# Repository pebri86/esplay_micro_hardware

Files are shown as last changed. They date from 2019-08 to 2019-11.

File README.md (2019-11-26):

# ESPlay Micro Hardware
This board is micro version (smaller device but same as powerfull as big brother EsPlay Hardware), an ESP 32 Based portable gaming console. See the project logs at my [hackaday] page. Also if you want this board without much effort, you can buy it at [Makerfabs Online Store] they sell the PCB Assembly so you can get the board which ready to play.
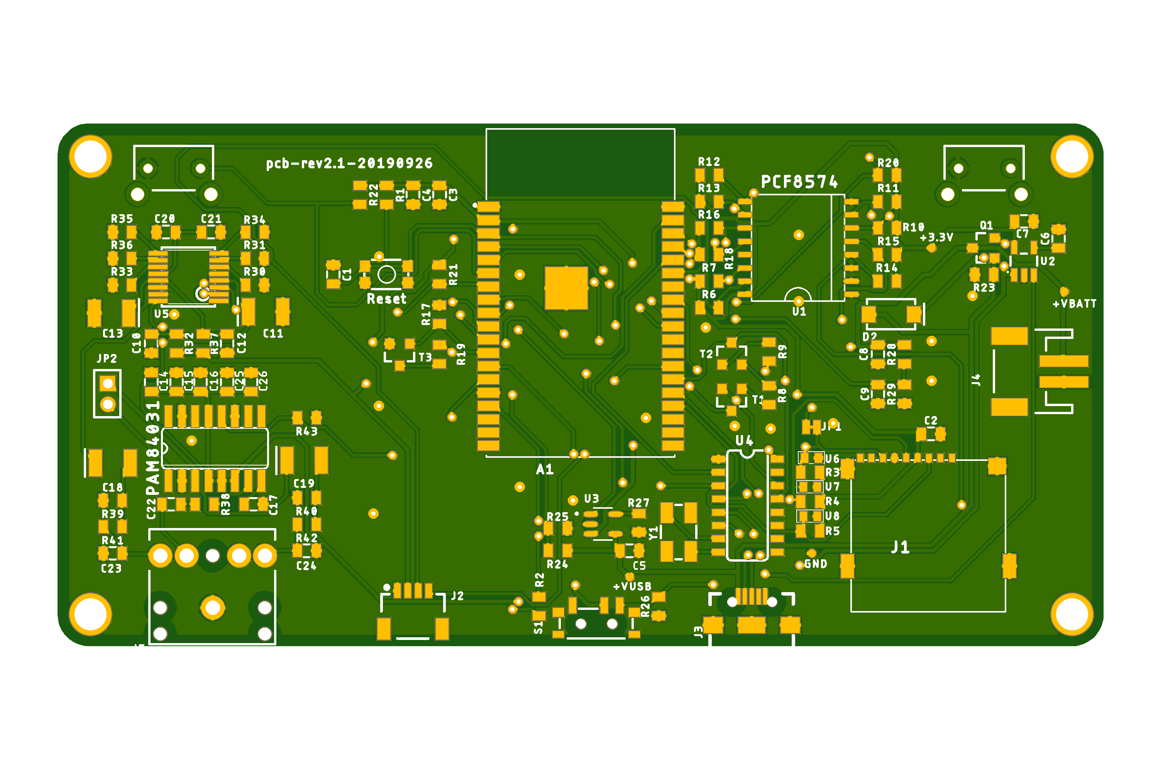
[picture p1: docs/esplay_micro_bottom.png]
bottom_layer

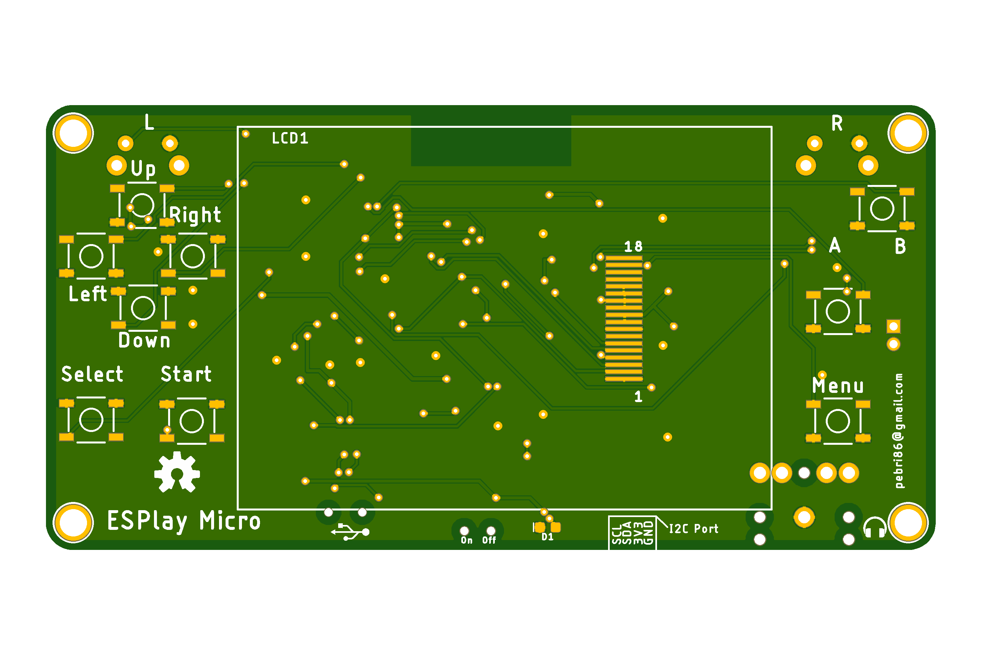
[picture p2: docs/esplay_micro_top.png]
top_layer


Featured
--------
- ESP32 WROVER, Dual core processor with Integrated 4MB Flash + 4MB PSRAM
- Integrated WIFI and Bluetooth 4 BLE
- 2,4" ILI9341 TFT Panel
- More button (expanded via PCF8574 I2C GPIO)
- Micro SD slot connected to SDMMC Host in 1 Line Mode for save GPIO pin
- Integrated I2S DAC via UDA1334A
- Integrated USB to Serial for programming and debugging using CH340C/G
- Built-in ~~TP4056~~ LTC4054 Li-Po charger
- ~~Touchscreen, yes resitive touchscreen of ili9341 now connected to ESP32 GPIO~~
- I2C port for expandable function
- 3,5mm Headphone jack
- Smaller Size, PCB only 100 x 50 mm.

Firmwares
---------
Flash this board with this [bootloader] for the ability flashing via sdcard, so you doesn't need computer to switch application firmware, and last but not least the emulator itself for playing the game [ESPlay Retro Emulation].

There is also collections of available compiled firmware (.fw) application files on my repo [Firmware Collections]

Changelogs
----------
### 01 Oct 2019
- Bugs fix brighness control issue
- Bugs fix autoreset circuit
- Bugs fix audiojack placement

### 27 Aug 2019
- Remove touchscreen control due to other function that more important
- Audio amplifier shutdown
- Audio amplifier chip change to PAM8304
- Change li-po charger with LTC4054
- Add Charger management sensing (USB plug and Chrge state)
- Add ESD Protection on SDCard
- Add status LED (charging) controlled via ESP32 GPIO

### 06 May 2019
- Add amplifier circuits for internal speaker.
- Add ground for EXP pin ESP32 Wrover module.
- Connect micro usb shield to ground.
- Remove some unnecessary vias.

[Makerfabs Online Store]: https://www.makerfabs.com/esplay-micro.html
[hackaday]: https://hackaday.io/project/166707-esplay-micro
[bootloader]: https://github.com/pebri86/esplay-base-firmware
[ESPlay Retro Emulation]: https://github.com/pebri86/esplay-retro-emulation
[Firmware Collections]: https://github.com/pebri86/esplay-micro-firmware-collections

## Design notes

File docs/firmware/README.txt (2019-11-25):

How to deploy bootloader and emulation firmware to ESPlay Micro

Preparation
-----------

1. Micro USB Cable
2. Micro SDCard
3. Install esptool
   >pip install esptool

Installation
------------

1. open the firmware folder and execute flash.bat under windows or flash.sh under linux (don't forget to make it executable first by chmod +x).
2. if the operation success the esplay will boot into bootloader menu.
3. copy esplay, mp3 and roms folder to root of microsd card.
4. put the card to ESPlay Micro sdcard slot.
5. turn on the board and the bootloader will show list of firmware file available in this case it will display esplay-retro-emu.fw and mp3-player_DAC.fw
6. To flash the firmware select the file then press A then Start, wait until flashing done then it will automatically restart and boot to application.
7. Place the rom of emulator on roms folder to the appropriate folder example game gear rom to gg folder, gameboy rom to gb folder and so on.

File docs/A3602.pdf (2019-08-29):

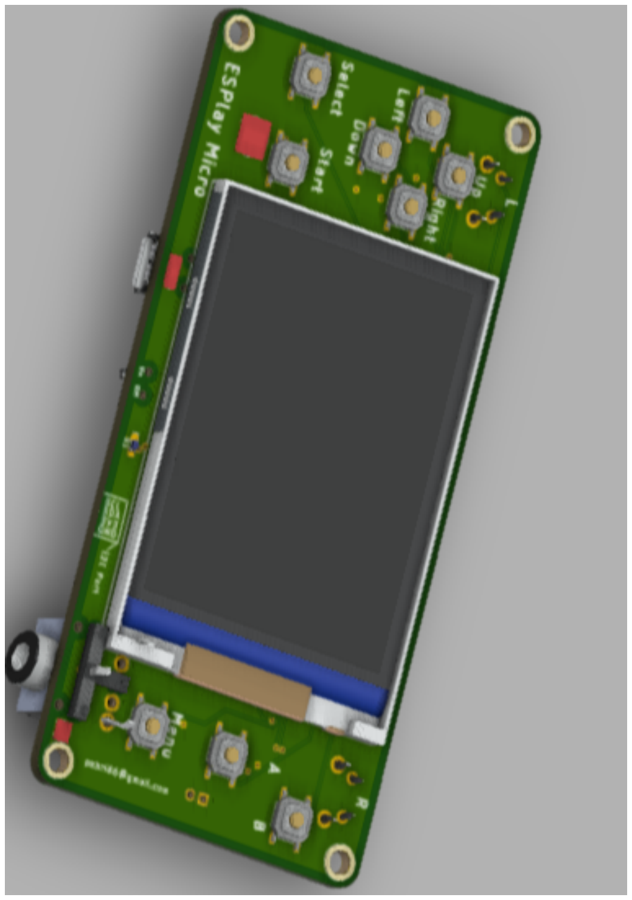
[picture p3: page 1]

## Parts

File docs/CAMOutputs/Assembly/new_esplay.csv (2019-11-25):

Qty | Value | Device | Package | Parts | Description | AVAILABILITY | BOM | DESCRIPTION | DIGI-KEY_PART_NUMBER | DIGI-KEY_PURCHASE_URL | MF | MP | PACKAGE | PRICE | PROD_ID | SF_ID | SF_SKU | VALUE
1 |  | JST_2MM_MALE | JST-2-SMD | J4 | JST 2MM MALE RA CONNECTOR |  |  |  |  |  |  |  |  |  | CONN-11443 | PRT-08612
9 |  | MOMENTARY-SWITCH-SPST-2-SMD-5.2MM | TACTILE_SWITCH_SMD_5.2MM | S2, S3, S4, S5, S6, S7, S8, S9, S11 | Momentary Switch (Pushbutton) - SPST - Two Circuits |  |  |  |  |  |  |  |  |  | SWCH-08247 |  | COM-08720
1 |  | PINHD-1X2_2.00 | 1X02M | JP2 | PIN HEADER
1 |  | QWIIC_CONNECTORJS-1MM | 1X04_1MM_RA | J2 | SparkFun I2C Standard Qwiic Connector |  |  |  |  |  |  |  |  |  | CONN-13694
1 |  | SWITCH-SPDT-SMD-RIGHT-ANGLE | SWITCH_SPST_SMD_A | S13 | Single Pole, Double Throw (SPDT) Switch |  |  |  |  |  |  |  |  |  | SWCH-10651 |  | COM-10860
1 |  | USB_MICRO-B_FEMALE-SMT | USB-B-MICRO-SMD | J3 | USB Type Micro-B Connector |  |  |  |  |  |  |  |  |  | CONN-11752
2 | 1 | 0.3OHM-0805-1/8W-1% | 0805 | R32, R37 | 0.3Ω resistor |  |  |  |  |  |  |  |  |  | RES-11622 |  |  | 0.3
1 | 1.1A/60V/600mΩ | MOSFET_PCH-SI2309DS | SOT23-3 | Q1 | P-channel MOSFETs |  |  |  |  |  |  |  |  |  | TRANS-08285 |  |  | 1.1A/60V/600mΩ
1 | 1.65K | 0.3OHM-0805-1/8W-1% | 0805 | R27 | 0.3Ω resistor |  |  |  |  |  |  |  |  |  | RES-11622 |  |  | 0.3
1 | 10 | 0.22OHM-0805-1/4W-1% | 0805 | R19 | 0.22Ω resistor |  |  |  |  |  |  |  |  |  | RES-09883 |  |  | 0.22
2 | 100 | 0.3OHM-0805-1/8W-1% | 0805 | R41, R42 | 0.3Ω resistor |  |  |  |  |  |  |  |  |  | RES-11622 |  |  | 0.3
2 | 100K | 0.22OHM-0805-1/4W-1% | 0805 | R17, R26 | 0.22Ω resistor |  |  |  |  |  |  |  |  |  | RES-09883 |  |  | 0.22
1 | 100K | 0.3OHM-0805-1/8W-1% | 0805 | R43 | 0.3Ω resistor |  |  |  |  |  |  |  |  |  | RES-11622 |  |  | 0.3
7 | 100nF | 2.2UF-0805-25V-(+80/-20%) | 0805 | C1, C4, C8, C9, C10, C12, C20 | 2.2µF ceramic capacitors |  |  |  |  |  |  |  |  |  | CAP-11624 |  |  | 2.2uF
18 | 10K | 0.22OHM-0805-1/4W-1% | 0805 | R1, R3, R4, R5, R8, R9, R10, R11, R12, R13, R14, R15, R16, R18, R20, R21, R22, R23 | 0.22Ω resistor |  |  |  |  |  |  |  |  |  | RES-09883 |  |  | 0.22
7 | 10K | 0.3OHM-0805-1/8W-1% | 0805 | R30, R31, R33, R34, R35, R36, R38 | 0.3Ω resistor |  |  |  |  |  |  |  |  |  | RES-11622 |  |  | 0.3
4 | 10nF | 2.2UF-0805-25V-(+80/-20%) | 0805 | C16, C17, C23, C24 | 2.2µF ceramic capacitors |  |  |  |  |  |  |  |  |  | CAP-11624 |  |  | 2.2uF
5 | 10uF | 2.2UF-0805-25V-(+80/-20%) | 0805 | C2, C7, C14, C21, C26 | 2.2µF ceramic capacitors |  |  |  |  |  |  |  |  |  | CAP-11624 |  |  | 2.2uF
1 | 12Mhz | CRYSTALSMD-5X3.2-4PAD | CRYSTAL-SMD-5X3.2-4PAD | Y1 | Crystals (Generic)
1 | 1A/40V/500mV | DIODE-SCHOTTKY-SS14 | SMA-DIODE | D2 | Schottky diode |  |  |  |  |  |  |  |  |  | DIO-08053 |  |  | 1A/40V/500mV
3 | 1uF | 2.2UF-0805-25V-(+80/-20%) | 0805 | C5, C15, C25 | 2.2µF ceramic capacitors |  |  |  |  |  |  |  |  |  | CAP-11624 |  |  | 2.2uF
1 | 2.2uF | 2.2UF-0805-25V-(+80/-20%) | 0805 | C3 | 2.2µF ceramic capacitors |  |  |  |  |  |  |  |  |  | CAP-11624 |  |  | 2.2uF
2 | 220K | 0.3OHM-0805-1/8W-1% | 0805 | R39, R40 | 0.3Ω resistor |  |  |  |  |  |  |  |  |  | RES-11622 |  |  | 0.3
1 | 220nF | 2.2UF-0805-25V-(+80/-20%) | 0805 | C22 | 2.2µF ceramic capacitors |  |  |  |  |  |  |  |  |  | CAP-11624 |  |  | 2.2uF
1 | 2K2 | 0.22OHM-0805-1/4W-1% | 0805 | R2 | 0.22Ω resistor |  |  |  |  |  |  |  |  |  | RES-09883 |  |  | 0.22
2 | 470K | 0.22OHM-0805-1/4W-1% | 0805 | R28, R29 | 0.22Ω resistor |  |  |  |  |  |  |  |  |  | RES-09883 |  |  | 0.22
1 | 470pF | 2.2UF-0805-25V-(+80/-20%) | 0805 | C6 | 2.2µF ceramic capacitors |  |  |  |  |  |  |  |  |  | CAP-11624 |  |  | 2.2uF
2 | 47K | 0.22OHM-0805-1/4W-1% | 0805 | R24, R25 | 0.22Ω resistor |  |  |  |  |  |  |  |  |  | RES-09883 |  |  | 0.22
4 | 47uF | 47UF-POLAR-EIA3528-10V-10% | EIA3528 | C11, C13, C18, C19 | 47µF polarized capacitors |  |  |  |  |  |  |  |  |  | CAP-08310 |  |  | 47uF
2 | 4K7 | 0.22OHM-0805-1/4W-1% | 0805 | R6, R7 | 0.22Ω resistor |  |  |  |  |  |  |  |  |  | RES-09883 |  |  | 0.22
3 | 600mA/40V | TRANS_NPN-MMBT2222AL | SOT23-3 | T1, T2, T3 | NPN transistor |  |  |  |  |  |  |  |  |  | TRANS-08049 |  |  | 600mA/40V
1 | AUDIO_JACK_3.5MM_PTH | AUDIO_JACK_3.5MM_PTH | AUDIO-JACK | J5 | Audio Jack |  |  |  |  |  |  |  |  |  | CONN-08774 | PRT-08032
1 | BLUE | LED-BLUE0603 | LED-0603 | D1 | Blue SMD LED |  |  |  |  |  |  |  |  |  | DIO-08575 |  |  | BLUE
1 | CH340G | CH340GSMD | SO016 | U4 | A simple USB 2.0 to Serial IC. |  |  |  |  |  |  |  |  |  | IC-13498 |  |  | CH340G
3 | ESD0402 | ESD0402 | ESD0402 | U6, U7, U8 | None
1 | ESP32-WROVER-I | ESP32-WROVER-I | XCVR_ESP32-WROVER-I | A1 | Module: combo; GPIO, I2C x2, I2S x2, SDIO, SPI x3, UART x3; U.FL | Unavailable |  | Module: combo | GPIO, I2C x2, I2S x2, SDIO, SPI x3, UART x3 | U.FL |  |  | Espressif Systems | ESP32-WROVER-I | Module Espressif Systems | None
1 | ILI9341-2.4 | ILI9341-2.4 | ILI9341-2.4 | LCD1
1 | JP Bootstrap | JUMPER-SMT_2_NC_TRACE_NO-SILK | SMT-JUMPER_2_NC_TRACE_NO-SILK | JP1 | Normally closed trace jumper
1 | L | MOMENTARY-SWITCH-SPST-PTH-RIGHT-ANGLE-KIT | TACTILE_SWITCH_PTH_RIGHT_ANGLE_KIT | S10 | Momentary Switch (Pushbutton) - SPST |  |  |  |  |  |  |  |  |  | CONN-10672 |  | COM-10791
1 | LTC4054LES5-4.2#TRPBF | LTC4054LES5-4.2#TRPBF | SOT95P280X100-5N | U3 | LTC4054L-4.2 - 150mA Standalone Linear Li-Ion Battery Charger in ThinSOT |  |  | LTC4054L-4.2 - 150mA Standalone Linear Li-Ion Battery Charger in ThinSOT | LTC4054LES5-4.2#TRPBFCT-ND | https://www.digikey.co.id/product-detail/en/linear-technology-analog-devices/LTC4054LES5-4.2-TRPBF/LTC4054LES5-4.2-TRPBFCT-ND/1888452 | Linear Technology/Analog | LTC4054LES5-4.2#TRPBF | SOT-23-5 Linear Technology
1 | MIC5219 3.3V | V_REG_MIC52193.3V | SOT23-5 | U2 | V_REG MIC5219 |  |  |  |  |  |  |  |  |  | VREG-09872 |  |  | MIC5219 3.3V
4 | MICROBUILDER_MOUNTINGHOLE3.0THIN | MICROBUILDER_MOUNTINGHOLE3.0THIN | MICROBUILDER_MOUNTINGHOLE_3.0_PLATEDTHIN | H1, H2, H3, H4 | Mounting Hole |  | EXCLUDE
1 | MICROSD-PUSH-OUT | MICROSD-PUSH-OUT | MICROSD-PUSH-OUT | J1 | T-Flash Push-Out Micro SD Card Reader
1 | PAM8403 | PAM8403 | SOP-16 | PAM84031 | Dual channel audio amplifier IC - PAM8403
1 | PCF8574 | PCF8574 | SO16 | U1 |  | Unavailable |  | Remote 8-Bit I/O Expander for I2C-Bus |  |  | Texas Instruments | PCF8574 | SOIC-16 Texas Instruments | None
1 | R | MOMENTARY-SWITCH-SPST-PTH-RIGHT-ANGLE-KIT | TACTILE_SWITCH_PTH_RIGHT_ANGLE_KIT | S12 | Momentary Switch (Pushbutton) - SPST |  |  |  |  |  |  |  |  |  | CONN-10672 |  | COM-10791
1 | RST | MOMENTARY-SWITCH-SPST-SMD-4.6X2.8MM | TACTILE_SWITCH_SMD_4.6X2.8MM | S1 | Momentary Switch (Pushbutton) - SPST |  |  |  |  |  |  |  |  |  | SWCH-13065
4 | TEST-POINT3 | TEST-POINT3 | PAD.03X.03 | TP1, TP2, TP3, TP4 | SparkFun Test Points
1 | UDA1334ATS | MICROBUILDER_AUDIO_I2S_UDA1334" | MICROBUILDER_SSOP16_4.4MM | U5 | UDA1334 I2C Audio DAC

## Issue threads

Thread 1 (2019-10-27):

Auto Reset circuit

gvoigtlaender, 2019-10-27:
Hi,

I wonder if the designed auto-reset circuit is working. On other schematics both DTR & RTS go to Base of one transistor and Emitter of other [1].
In esplay_micro schematic DTR goes to the Collector of T2. Is that on purpose?

[1] http://www.basicpi.org/wp-content/uploads/2018/02/ESP32_CH340G.png

BR,
Georg

pebri86, 2019-10-27:
Hi, thanks for opening an issue. Yes it is my mistake and I've updated the local files but not push to github yet, tomorrow i will update the repository. actually this board is already available on the makerfabs online store [Here](https://www.makerfabs.com/esplay-micro.html) and this board version should have the correct auto reset circuit.

thanks,
regards.

pebri86, 2019-10-28:
Hi, I've updated the repo. Thanks for reporting the issue.

Regards.

Closed 2019-10-28.

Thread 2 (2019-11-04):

Max brightness still too dark

pebri86, 2019-11-04:
**ISSUE DESCRIPTION**
Set brightness setting to maximum but it still too dark.

**How to reproduce**
Set brightness to maximum then check the LCD still too dark.

Hardware issue? or change duty max value (PWM)

Closed 2019-11-04.

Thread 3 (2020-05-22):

slow battery charging

pizvizdik, 2020-05-22:
hello pebri,

every battery i tried is charging only at 50mA rate which is pretty slow i think (about 20 hours of charging time with 1000mAh battery).. i also tried different usb power supplies and micro USB cables.. is it caused by scheme design or there is possible problem?

thank you

pebri86, 2020-05-24:
Hi,
Please check value of R27 it should be 1.65k to deliver 600mA charge rate.

pizvizdik, 2020-05-28:
hi, i just checked R27, resistance seems to be OK (about 1.66K).. still no higher current than 50mA.. do you have any other ideas please?

pebri86, 2020-05-29:
> hi, i just checked R27, resistance seems to be OK (about 1.66K).. still no higher current than 50mA.. do you have any other ideas please?

Try changing those Resistor with 1K value

pizvizdik, 2020-05-29:
thank you very much pebri ^^ i just soldered 1K resistor and charge rate goes up to about 100mA :3 not sure how to calculate R27 resistance for at least 800mA?

pebri86, 2020-05-30:
Ah, i think you have another variant of LTC4054 ic. I originally designed with LTC4054-4.2 which the datasheet said the charge current 1000 times the current out the PROG pin and the formula is

Rprog = 1000 / Ichrg

so if you have 1K value with result of 100mA then your LTC variant have 100 times not 1000. So Rprog = 100/Ichrg.

Which means to get 800mA try change rprog with 125 Ohm.

pizvizdik, 2020-06-14:
finaly had time to swap that little guy, now everything is working just fine :3
thank you very much for your help :)

Closed 2020-06-14.

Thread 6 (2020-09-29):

Missing BOM

ronangaillard, 2020-09-29:
Hi,

I'm pretty sur I saw a BOM for this project with DK References.

If I'm not mistaken could you add it to your repo ?

If not where can I find it ?

Thanks

pebri86, 2020-10-08:
Hi, sorry for waiting.
I've been busy for a while.
The BOM should be in the repository, check doc/camoutputs/assembly folder in CSV file.

ronangaillard, 2020-10-09:
Thanks !
I thought I found one with dk refs but I must be confused !

Closed 2020-10-09.

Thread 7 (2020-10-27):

The game in the NES emulator cannot be saved. What is the problem?

38293312, 2020-10-27:
The game in the NES emulator cannot be saved. What is the problem?

pebri86, 2020-11-02:
Hi,
I can't reproduce the issue, my build is working fine. So could you show the debug serial output? which version of esplay firmware did you use or which NES rom ( or is happen on all ROM ?).

38293312, 2020-11-02:
> 嗨，
> 我无法重现该问题，我的构建工作正常。那么，您可以显示调试串行输出吗？您使用了哪个版本的esplay固件或哪个NES rom（或在所有ROM上都发生了？）。

I am using "v2.2-esplay-micro.fw". IDF v3.3-202gefdddbb25-dirty. While the NES emulator and SEGA emulator are running the game, pressing the "menu" pop-up "volume" "brightness" "SAVE" in "SAVE" cannot save the game progress. In the process of saving the game in the SEGA emulator, the game can’t be saved or the "SAVE" in the "menu" button is pressed

pebri86, 2020-11-02:
Which ROM file did you play? I will tried reproduce the issue cause mine is no problem.

38293312, 2020-11-02:
> 您播放了哪个ROM文件？我会尝试重现该问题，因为我的没有问题。

I don't know whether "Contra.nes" can be saved normally on the NES emulator. SEGA has the same problem. I just tried the GBC game "pokemon gold.gbc" and it can’t be saved.

pebri86, 2020-11-02:
It's strange, could you show the folder structure on the sdcard? actually it's better if you can post the serial debug log.

38293312, 2020-11-02:
Show folder structure on my sdcard，I'm very sorry, I don't understand how the serial debug log is debugged, can you tell me?

     audio---*.mp3
     esplay---firmware
     roms---col
            |---gb
            |---bgc
            |---gg
            |---nes
            |---sms

38293312, 2020-11-02:
> 奇怪，您能在sdcard上显示文件夹结构吗？实际上，最好是可以发布串行调试日志。

Show folder structure on my sdcard，I'm very sorry, I don't understand how the serial debug log is debugged, can you tell me?

 audio---*.mp3
 esplay---firmware
 roms---col
        |---gb
        |---bgc
        |---gg
        |---nes
        |---sms

pebri86, 2020-11-02:
> I'm very sorry, I don't understand how the serial debug log is debugged, can you tell me?

You missing data folder under esplay folder, please make folder for each emulator system at esplay->data
for example data folder for nes system will be /esplay/data/nes.

38293312, 2020-11-02:
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

Hahaha, great, it turned out to be a problem caused by insufficient files. After your explanation, after I created the folder now, the NES archive is now normal. However, the archive of GBC and COL simulators is not normal after trying twice, and there is no SAV file in the corresponding GBC and COL folders. Strange!

38293312, 2020-11-02:
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

There is a GBC game that cannot be saved normally. It may be caused by the game ROM. I used another version and it is normal. Now there is no problem. Thank you for your help!

pebri86, 2020-11-02:
Great to hear that from you. Yes some rom are not fully compatible with the emulators but almost roms are compatible.

Now I'll close the issue.

Closed 2020-11-02.

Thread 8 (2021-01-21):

License

niutech, 2021-01-21:
What's the license of ESPlay Micro design files, bootloader and firmware? Is it open source?

pebri86, 2021-01-21:
Hi,
Yes the projects are open source,  you're free to modify and made your own based on this projects, but if you don't mind you can shared your modified version with us, so we can improve the projects together. Thank you

dunk8888, 2021-02-10:
Hi what was the problem with resistor, my backlight doesnt work when using mp3 player, also most firmware. My resistor value says 100. Witch is 10 ohm i think, do i need to switch it out?

Aleyhanz, 2025-07-26:
Hi kak Pebri,apakah bisa custom project untuk TFT 8 bit

Aleyhanz, 2025-07-26:
Apakah support lcd 8bit.dengan keterbatasan pinout esp32.thank you

Pada Sab, 26 Jul 2025 21.50, Fuji Pebri ***@***.***> menulis:

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

Aleyhanz, 2025-07-28:
Saya masih belum paham dengan esp-idf .barangkali kakak  bersedia bikin project untuk TFT 8bit.
Rencana pakai lcd ili9341 8bit dan esp32s3 N16R8 dev modul yg banyak GPIO nya.thanks kak

Aleyhanz, 2025-08-02:
Maaf kak apakah firmware ini ada versi binariesnya

pebri86, 2025-08-04:
ada di sini [esplay retro emulation](https://www.google.com/url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)

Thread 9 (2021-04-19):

BOM table display error

LuckyFishGeek, 2021-04-19:
I use Office 2013 to open the display seems incorrect.Or is my Character Encoding set?

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

Thank you this very good project

pebri86, 2021-04-19:
Hi, maybe your encoding or try using import the csv file instead opening it.

Closed 2021-04-19.

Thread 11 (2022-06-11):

Is there a problem that the CS(Chip Select) pin of TF card is not connected?

eggfly, 2022-06-11:
As title 😄
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

pebri86, 2022-06-11:
i designed it using 1-bit sdmmc connection mode and the cs pin is not required.

eggfly, 2022-06-11:
OH I understand now. And when using sdmmc mode these three sdio is also a must?

pebri86, 2022-06-11:
> OH I understand now. And when using sdmmc mode these three sdio pull up resistors are also a must? Beside SPI mode three resistors is not needed.

yes you're right you can read idf documentation for details how to work with sdcard with sdmmc mode and sdspi mode

eggfly, 2022-06-12:
Thank u very much.

Closed 2022-06-12.

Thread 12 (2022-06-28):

ILI9342 smaller screen?

eggfly, 2022-06-28:
Hi! Thank you for such a great project! I have a small question: I found this ILI9342 source code in firmware project:
https://github.com/pebri86/esplay-retro-emulation/blob/cf68ea80ea34987592b4fb1ba650a074ea85b839/esplay-sdk/esplay-components/esplay-hal/src/ili9342.c

Does that mean we can switch to a smaller screen than 2.4-inch screen (2.0-inch 320x240 TFT screen)?

Thank you!

32teeth, 2022-07-01:
> ILI9342 Support

Yes, any ILI934/C LCD will work with this.

> Things to consider

If it is a **C** variant (ILI9342C) there are a few addresses to add / omit. Take a look at our [odroid_display.c](https://github.com/retro-esp32/RetroESP32/blob/master/Launchers/retro-esp32/components/odroid/odroid_display.c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) specifically [this line](https://github.com/retro-esp32/RetroESP32/blob/master/Launchers/retro-esp32/components/odroid/odroid_display.c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)

```
{0x36, {(MADCTL_MX | MADCTL_MY | TFT_RGB_BGR)}, 1},
```

Closed 2022-06-28.

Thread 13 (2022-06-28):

What is the JP1 bootstrap between IO2 and IO0 used for?

eggfly, 2022-06-28:
Hi, I'm learning the ESPlay hardware design, I found this jumper between tf card's `dat0` pin and IO0 pin, what is it used for?

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

Forgive me for using the issue system to discuss my question, and thank you very much!

eggfly, 2022-06-28:
Oh I see this 😄:

https://docs.espressif.com/projects/esp-idf/en/latest/esp32/api-reference/peripherals/sd_pullup_requirements.html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

Closed 2022-06-29.

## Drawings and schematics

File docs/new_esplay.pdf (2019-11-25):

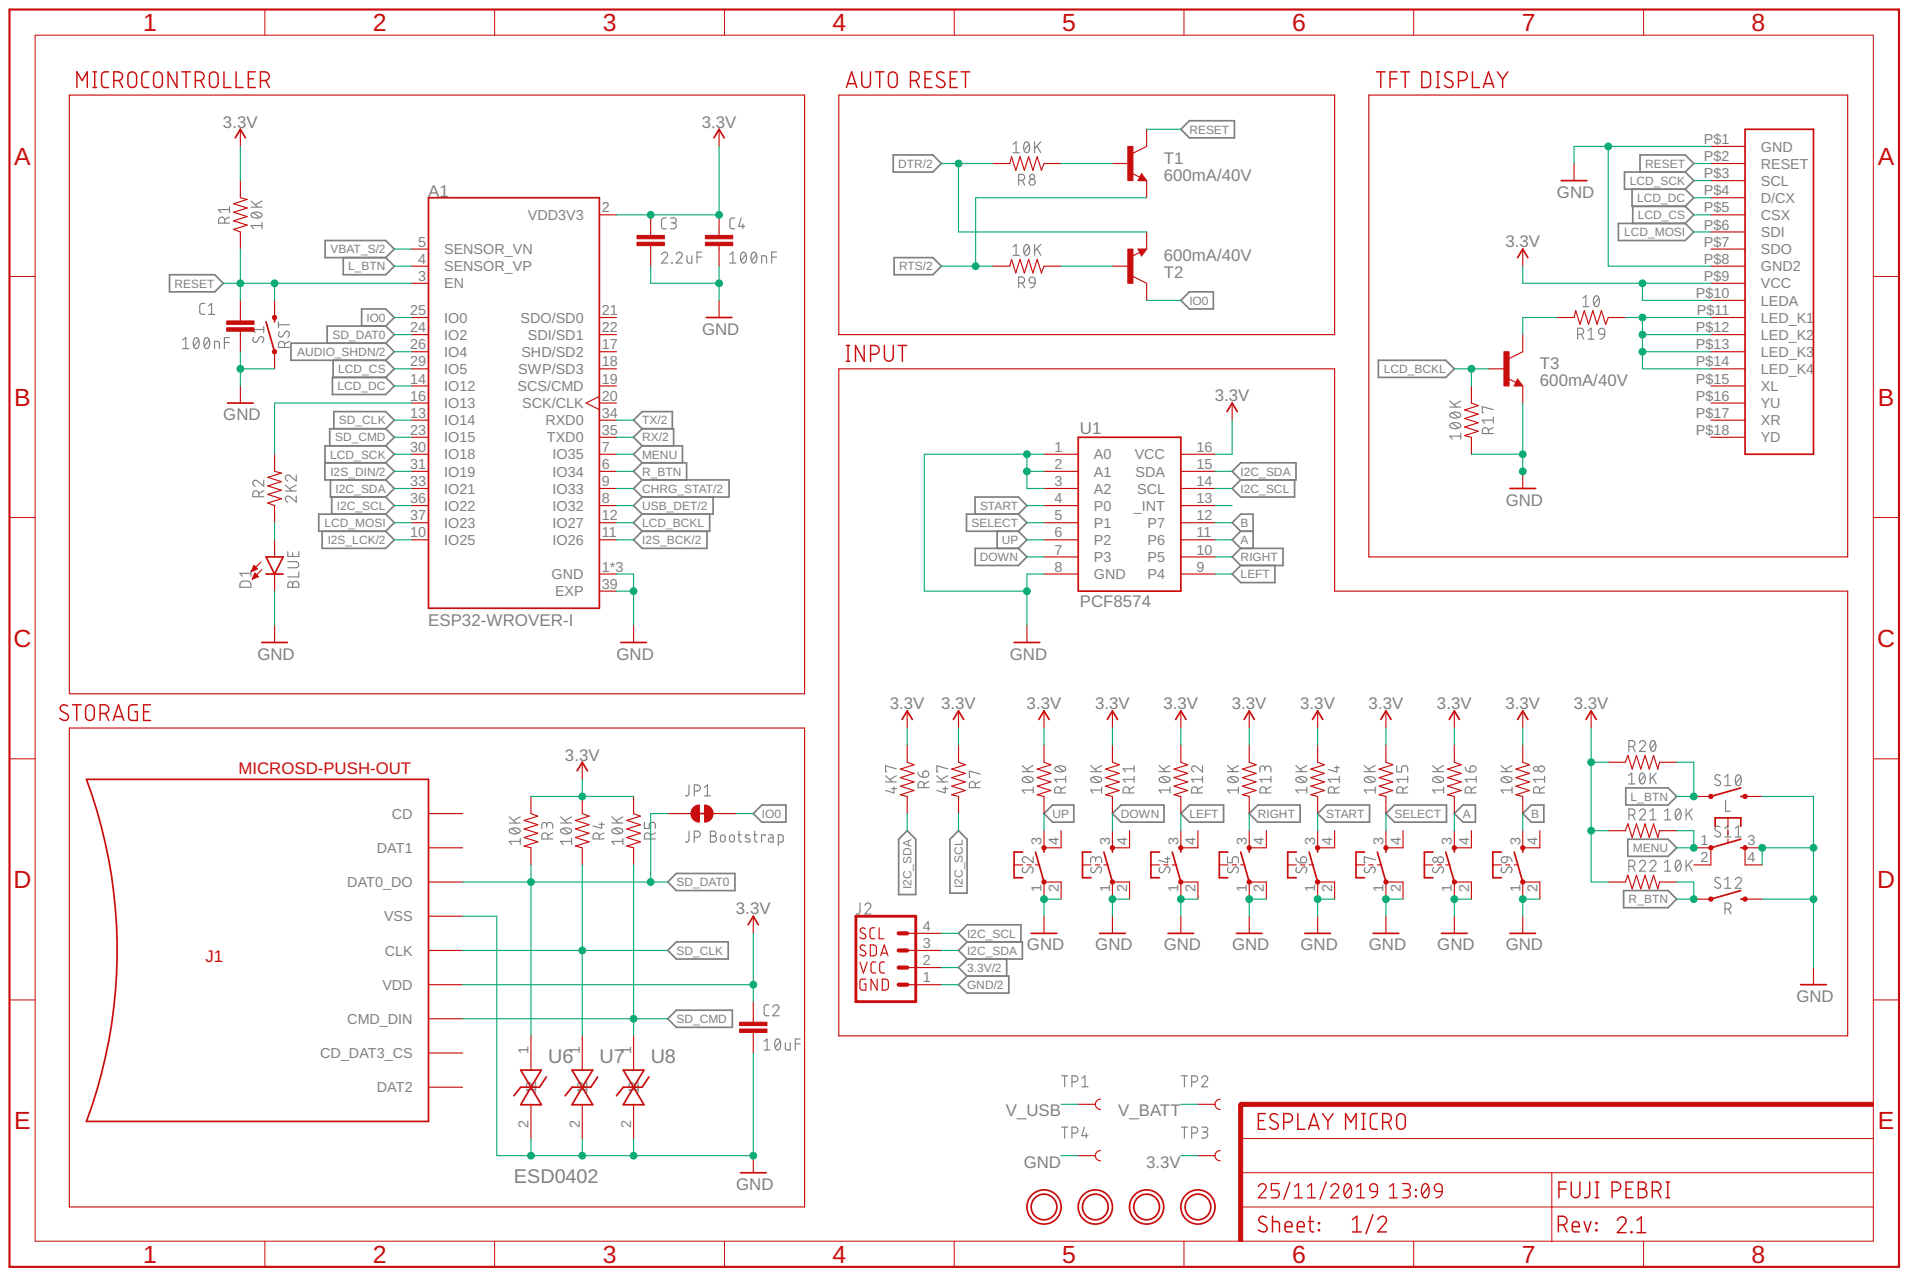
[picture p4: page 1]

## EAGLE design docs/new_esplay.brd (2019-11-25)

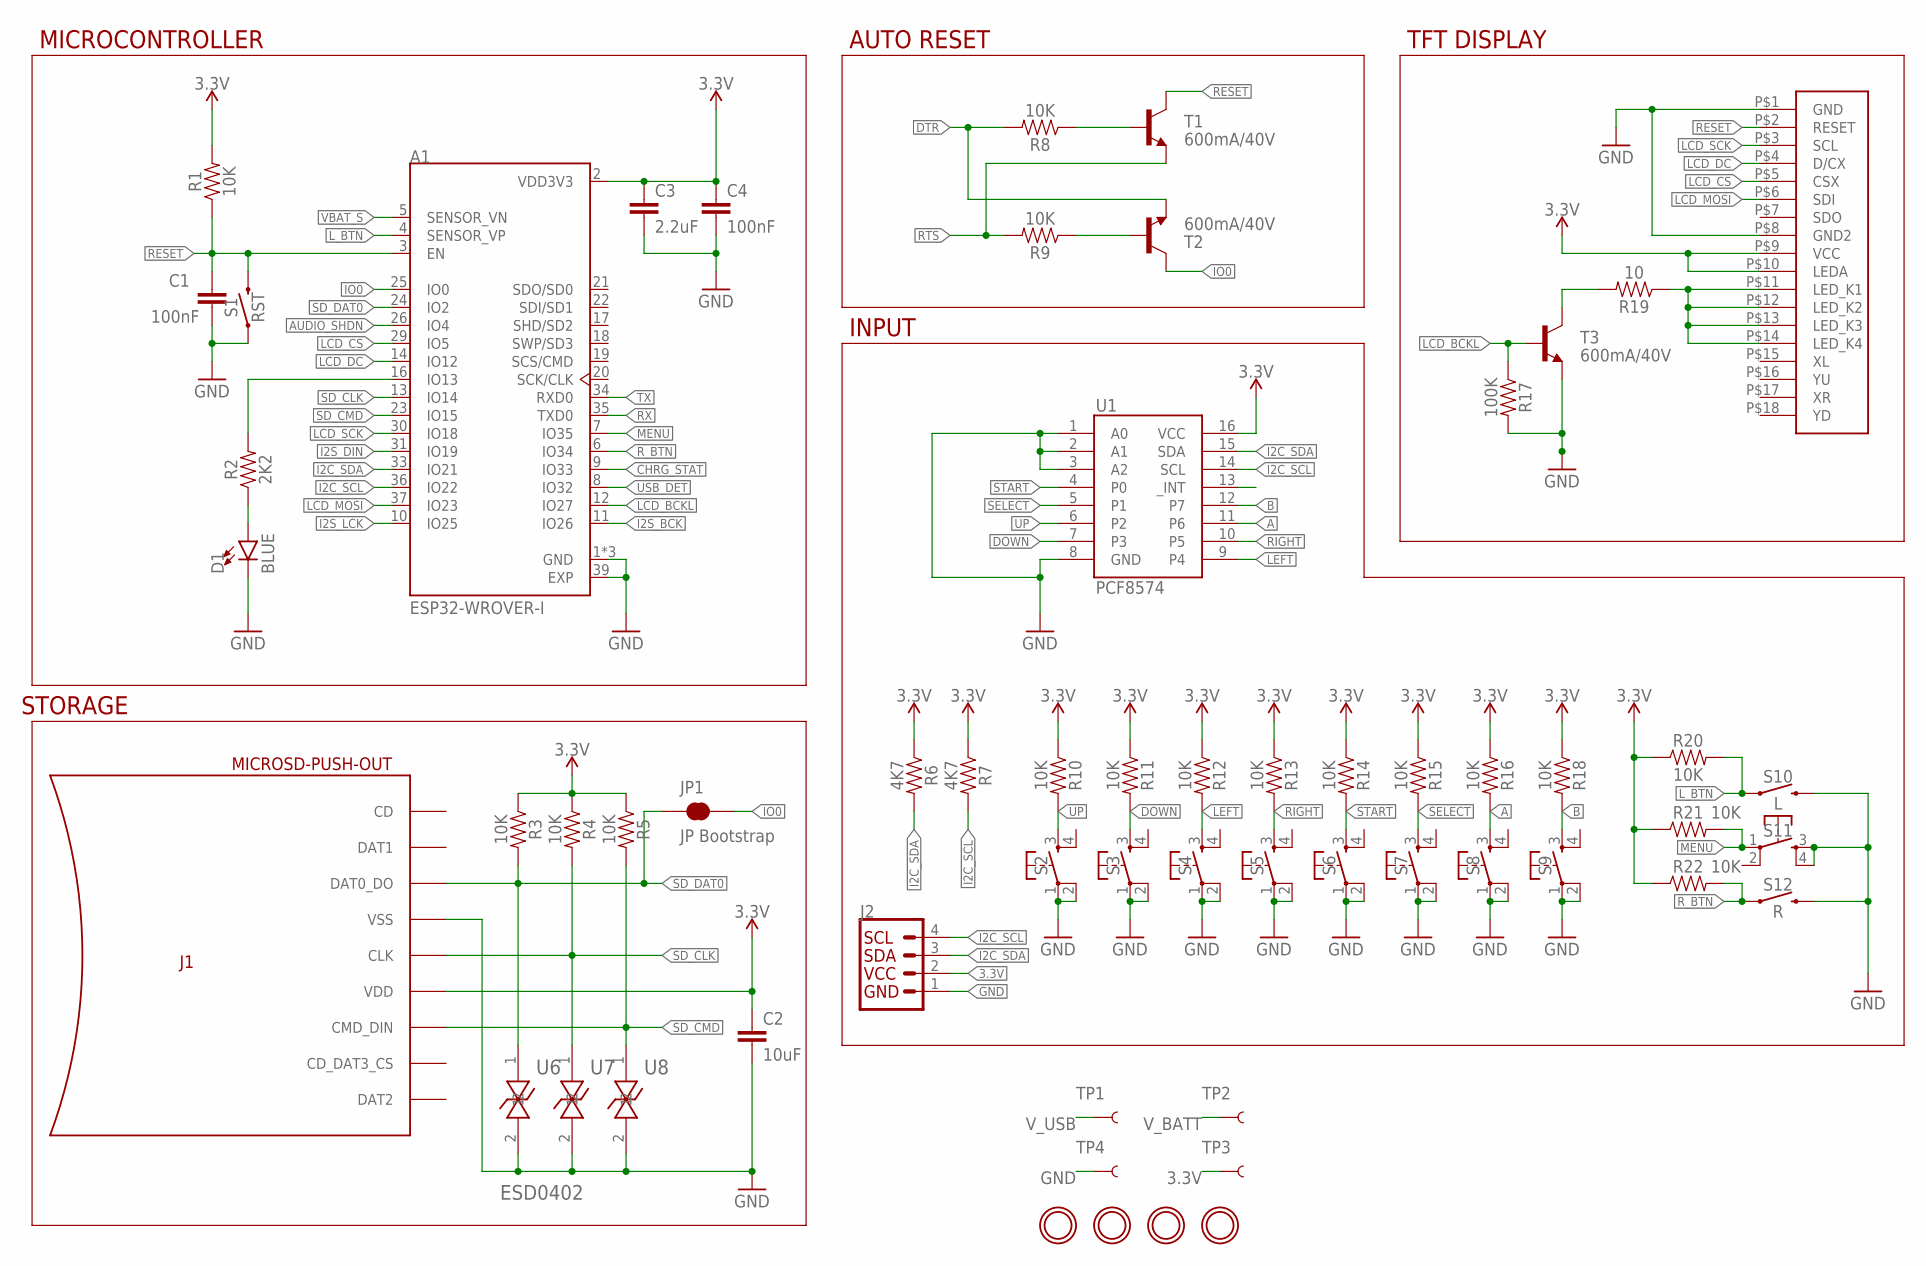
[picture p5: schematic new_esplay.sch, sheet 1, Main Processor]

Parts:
A1: ESP32-WROVER-I; XCVR_ESP32-WROVER-I
C1, C4: 100nF; 0805
C2: 10uF; 0805
C3: 2.2uF; 0805
D1: BLUE; LED-0603
H1, H2, H3, H4: MICROBUILDER_MOUNTINGHOLE3.0THIN; MICROBUILDER_MOUNTINGHOLE_3.0_PLATEDTHIN
J1: MICROSD-PUSH-OUT
J2: QWIIC_CONNECTORJS-1MM; 1X04_1MM_RA
JP1: JP Bootstrap; SMT-JUMPER_2_NC_TRACE_NO-SILK
LCD1: ILI9341-2.4
R1, R3, R4, R5, R8, R9, R10, R11, R12, R13, R14, R15, R16, R18, R20, R21, R22: 10K; 0805
R2: 2K2; 0805
R6, R7: 4K7; 0805
R17: 100K; 0805
R19: 10; 0805
S1: RST; TACTILE_SWITCH_SMD_4.6X2.8MM
S2, S3, S4, S5, S6, S7, S8, S9, S11: MOMENTARY-SWITCH-SPST-2-SMD-5.2MM; TACTILE_SWITCH_SMD_5.2MM
S10: L; TACTILE_SWITCH_PTH_RIGHT_ANGLE_KIT
S12: R; TACTILE_SWITCH_PTH_RIGHT_ANGLE_KIT
T1, T2, T3: 600mA/40V; SOT23-3
TP1, TP2, TP3, TP4: TEST-POINT3; PAD.03X.03
U1: PCF8574; SO16
U6, U7, U8: ESD0402

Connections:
3.3V: A1.2 (VDD3V3), C2.1, C3.1, C4.1, J1.4 (VDD), J2.2, LCD1.P$9 (VCC), LCD1.P$10 (LEDA), R1.2, R3.1, R4.1, R5.1, R6.1, R7.1, R10.1, R11.1, R12.1, R13.1, R14.1, R15.1, R16.1, R18.1, R20.1, R21.1, R22.1, TP3.P$1, U1.16 (VCC); also elsewhere on the board
A: R16.2, S8.3, U1.11 (P6)
AUDIO_SHDN: A1.26 (IO4); also elsewhere on the board
B: R18.2, S9.3, U1.12 (P7)
CHRG_STAT: A1.9 (IO33); also elsewhere on the board
DOWN: R11.2, S3.3, U1.7 (P3)
DTR: R8.2, T2.2 (E); also elsewhere on the board
GND: A1.1 (GND), A1.15 (GND), A1.38 (GND), A1.39 (EXP), C1.2, C2.2, C3.2, C4.2, D1.C, J1.6 (VSS), J1.G1 (VSS), J1.G2 (VSS), J1.G3 (VSS), J1.G4 (VSS), J2.1, LCD1.P$1 (GND), LCD1.P$8 (GND2), R17.2, S1.1, S1.2 (1), S2.1, S2.2, S3.1, S3.2, S4.1, S4.2, S5.1, S5.2, S6.1, S6.2, S7.1, S7.2, S8.1, S8.2, S9.1, S9.2, S10.2, S11.3, S11.4, S12.2, T3.2 (E), TP4.P$1, U1.1 (A0), U1.2 (A1), U1.3 (A2), U1.8 (GND), U6.2, U7.2, U8.2; also elsewhere on the board
I2C_SCL: A1.36 (IO22), J2.4, R7.2, U1.14 (SCL)
I2C_SDA: A1.33 (IO21), J2.3, R6.2, U1.15 (SDA)
I2S_BCK: A1.11 (IO26); also elsewhere on the board
I2S_DIN: A1.31 (IO19); also elsewhere on the board
I2S_LCK: A1.10 (IO25); also elsewhere on the board
IO0: A1.25 (IO0), JP1.2, T2.3 (C)
LCD_BCKL: A1.12 (IO27), R17.1, T3.1 (B)
LCD_CS: A1.29 (IO5), LCD1.P$5 (CSX)
LCD_DC: A1.14 (IO12), LCD1.P$4 (D/CX)
LCD_MOSI: A1.37 (IO23), LCD1.P$6 (SDI)
LCD_SCK: A1.30 (IO18), LCD1.P$3 (SCL)
LEFT: R12.2, S4.3, U1.9 (P4)
L_BTN: A1.4 (SENSOR_VP), R20.2, S10.1
MENU: A1.7 (IO35), R21.2, S11.1
unnamed: A1.16 (IO13), R2.2
unnamed: D1.A, R2.1
unnamed: R19.2, T3.3 (C)
unnamed: LCD1.P$11 (LED_K1), LCD1.P$12 (LED_K2), LCD1.P$13 (LED_K3), LCD1.P$14 (LED_K4), R19.1
unnamed: R8.1, T1.1 (B)
unnamed: R9.1, T2.1 (B)
RESET: A1.3 (EN), C1.1, LCD1.P$2 (RESET), R1.1, S1.3 (2), S1.4 (2), T1.3 (C)
RIGHT: R13.2, S5.3, U1.10 (P5)
RTS: R9.2, T1.2 (E); also elsewhere on the board
RX: A1.35 (TXD0); also elsewhere on the board
R_BTN: A1.6 (IO34), R22.2, S12.1
SD_CLK: A1.13 (IO14), J1.5 (CLK), R4.2, U7.1
SD_CMD: A1.23 (IO15), J1.3 (CMD_DIN), R5.2, U8.1
SD_DAT0: A1.24 (IO2), J1.7 (DAT0_DO), JP1.1, R3.2, U6.1
SELECT: R15.2, S7.3, U1.5 (P1)
START: R14.2, S6.3, U1.4 (P0)
TX: A1.34 (RXD0); also elsewhere on the board
UP: R10.2, S2.3, U1.6 (P2)
USB_DET: A1.8 (IO32); also elsewhere on the board
VBAT_S: A1.5 (SENSOR_VN); also elsewhere on the board
V_BATT: TP2.P$1; also elsewhere on the board
V_USB: TP1.P$1; also elsewhere on the board

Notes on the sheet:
INPUT
TFT DISPLAY
AUTO RESET
STORAGE
MICROCONTROLLER

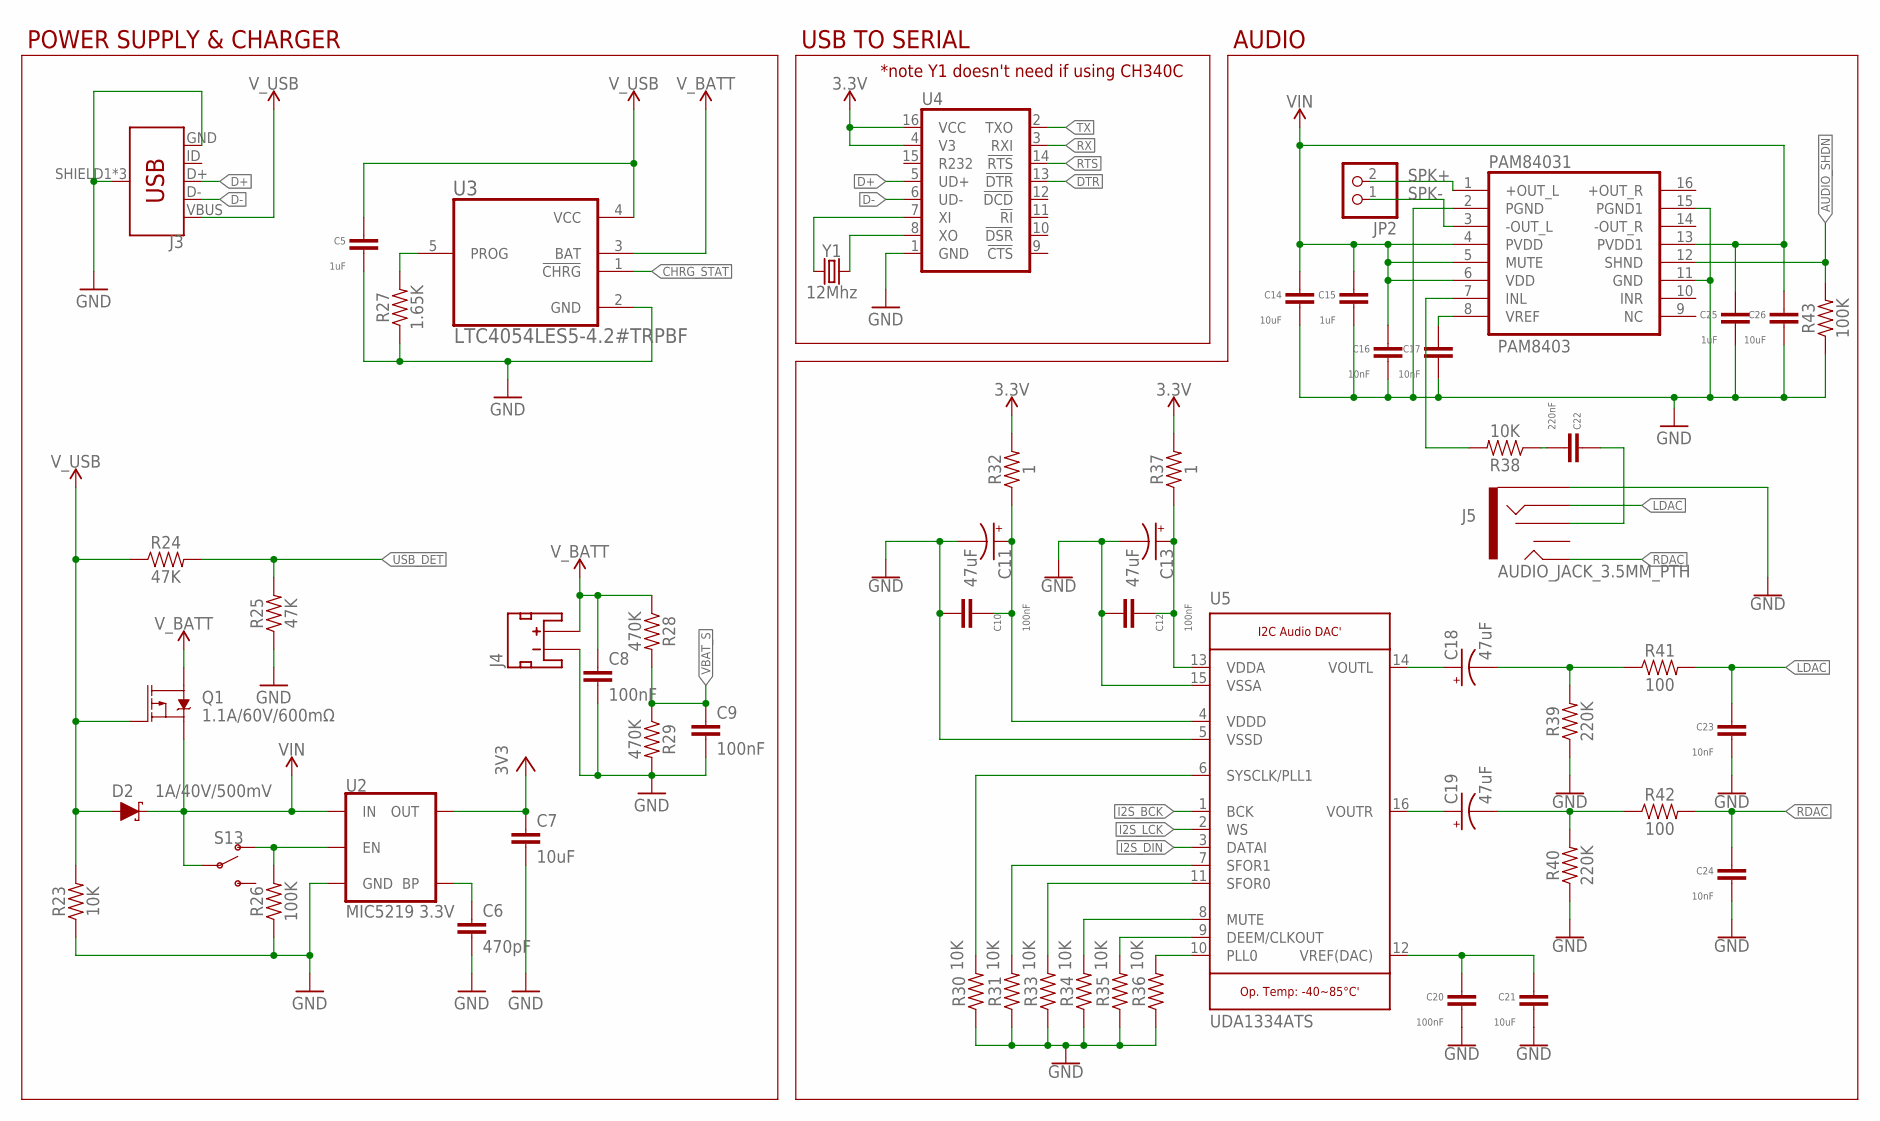
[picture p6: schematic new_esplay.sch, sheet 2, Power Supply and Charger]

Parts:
C5, C15, C25: 1uF; 0805
C6: 470pF; 0805
C7, C14, C21, C26: 10uF; 0805
C8, C9, C10, C12, C20: 100nF; 0805
C11, C13, C18, C19: 47uF; EIA3528
C16, C17, C23, C24: 10nF; 0805
C22: 220nF; 0805
D2: 1A/40V/500mV; SMA-DIODE
J3: USB_MICRO-B_FEMALE-SMT; USB-B-MICRO-SMD
J4: JST_2MM_MALE; JST-2-SMD
J5: AUDIO_JACK_3.5MM_PTH; AUDIO-JACK
JP2: PINHD-1X2_2.00; 1X02M
PAM84031: PAM8403; SOP-16
Q1: 1.1A/60V/600mΩ; SOT23-3
R23, R30, R31, R33, R34, R35, R36, R38: 10K; 0805
R24, R25: 47K; 0805
R26, R43: 100K; 0805
R27: 1.65K; 0805
R28, R29: 470K; 0805
R32, R37: 1; 0805
R39, R40: 220K; 0805
R41, R42: 100; 0805
S13: SWITCH-SPDT-SMD-RIGHT-ANGLE; SWITCH_SPST_SMD_A
U2: MIC5219 3.3V; SOT23-5
U3: LTC4054LES5-4.2#TRPBF; SOT95P280X100-5N
U4: CH340G; SO016
U5: UDA1334ATS; MICROBUILDER_SSOP16_4.4MM
Y1: 12Mhz; CRYSTAL-SMD-5X3.2-4PAD

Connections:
3.3V: C7.1, R32.2, R37.2, U2.5 (OUT), U4.4 (V3), U4.16 (VCC); also elsewhere on the board
AUDIO_SHDN: PAM84031.12 (SHND), R43.2; also elsewhere on the board
CHRG_STAT: U3.1 (!CHRG); also elsewhere on the board
D+: J3.D+, U4.5 (UD+)
D-: J3.D-, U4.6 (UD-)
DTR: U4.13 (!DTR); also elsewhere on the board
GND: C5.1, C6.2, C7.2, C8.2, C9.2, C10.1, C11.C (-), C12.1, C13.C (-), C14.1, C15.1, C16.1, C17.1, C20.1, C21.1, C23.1, C24.1, C25.1, C26.1, J3.GND, J3.SHIELD1 (SHIELD), J3.SHIELD2 (SHIELD), J3.SHIELD3 (SHIELD), J4.1 (-), J5.SLEEVE, PAM84031.2 (PGND), PAM84031.11 (GND), PAM84031.15 (PGND1), R23.1, R25.1, R26.1, R27.1, R29.2, R30.1, R31.1, R33.1, R34.1, R35.1, R36.1, R39.1, R40.1, R43.1, U2.2 (GND), U3.2 (GND), U4.1 (GND), U5.5 (VSSD), U5.15 (VSSA); also elsewhere on the board
I2S_BCK: U5.1 (BCK); also elsewhere on the board
I2S_DIN: U5.3 (DATAI); also elsewhere on the board
I2S_LCK: U5.2 (WS); also elsewhere on the board
LDAC: C23.2, J5.RING, R41.2
unnamed: R27.2, U3.5 (PROG)
unnamed: U4.7 (XI), Y1.3 (2)
unnamed: C18.A (+), U5.14 (VOUTL)
unnamed: U4.8 (XO), Y1.1
unnamed: R26.2, S13.1 (O), U2.3 (EN)
unnamed: C6.1, U2.4 (BP)
unnamed: C19.A (+), U5.16 (VOUTR)
unnamed: C17.2, PAM84031.8 (VREF)
unnamed: PAM84031.7 (INL), R38.2
unnamed: C18.C (-), R39.2, R41.1
unnamed: C19.C (-), R40.2, R42.1
unnamed: C12.2, C13.A (+), R37.1, U5.13 (VDDA)
unnamed: C20.2, C21.2, U5.12 (VREF(DAC))
unnamed: C10.2, C11.A (+), R32.1, U5.4 (VDDD)
unnamed: C22.1, R38.1
unnamed: R30.2, U5.6 (SYSCLK/PLL1)
unnamed: R31.2, U5.7 (SFOR1)
unnamed: R33.2, U5.11 (SFOR0)
unnamed: R34.2, U5.8 (MUTE)
unnamed: R35.2, U5.9 (DEEM/CLKOUT)
unnamed: R36.2, U5.10 (PLL0)
unnamed: C22.2, J5.RSH
RDAC: C24.2, J5.TIP, R42.2
RTS: U4.14 (!RTS); also elsewhere on the board
RX: U4.3 (RXI); also elsewhere on the board
SPK+: JP2.2, PAM84031.1 (+OUT_L)
SPK-: JP2.1, PAM84031.3 (-OUT_L)
TX: U4.2 (TXO); also elsewhere on the board
USB_DET: R24.2, R25.2; also elsewhere on the board
VBAT_S: C9.1, R28.2, R29.1; also elsewhere on the board
VIN: C14.2, C15.2, C16.2, C25.2, C26.2, D2.C, PAM84031.4 (PVDD), PAM84031.5 (MUTE), PAM84031.6 (VDD), PAM84031.13 (PVDD1), Q1.2 (S), S13.2, U2.1 (IN)
V_BATT: C8.1, J4.2 (+), Q1.3 (D), R28.1, U3.3 (BAT); also elsewhere on the board
V_USB: C5.2, D2.A, J3.VBUS, Q1.1 (G), R23.2, R24.1, U3.4 (VCC); also elsewhere on the board

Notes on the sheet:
POWER SUPPLY & CHARGER
USB TO SERIAL
AUDIO
*note Y1 doesn't need if using CH340C

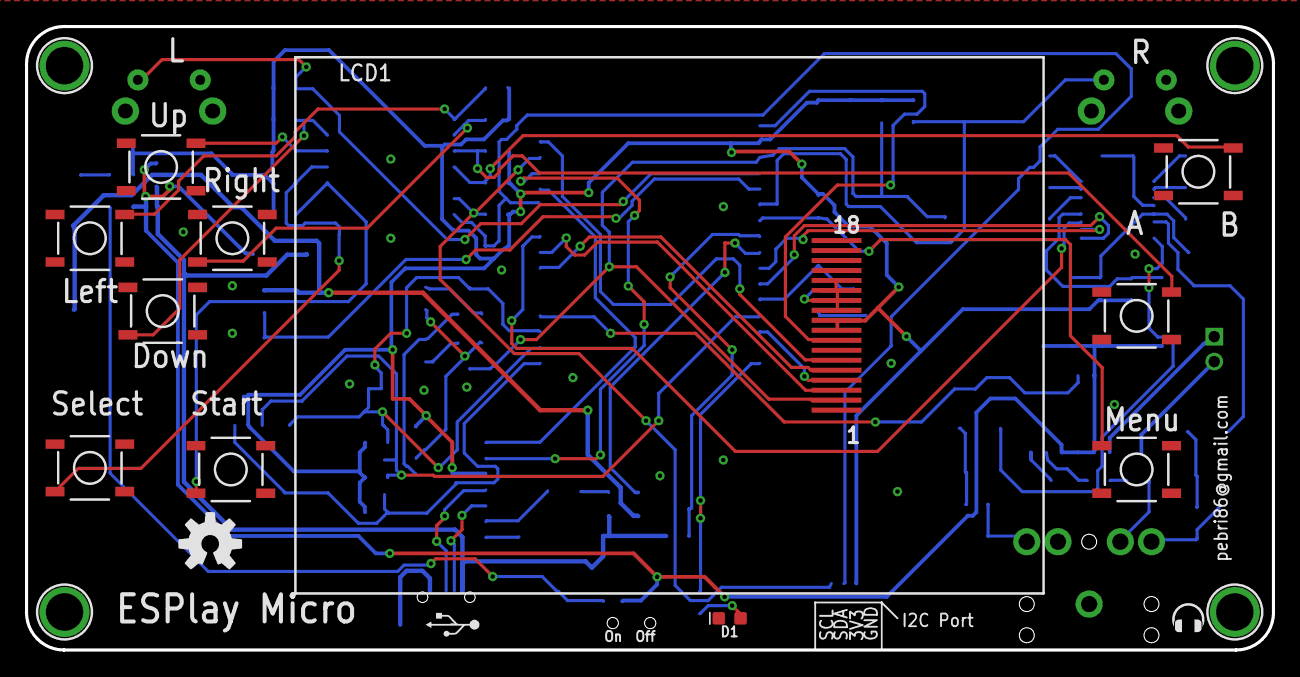
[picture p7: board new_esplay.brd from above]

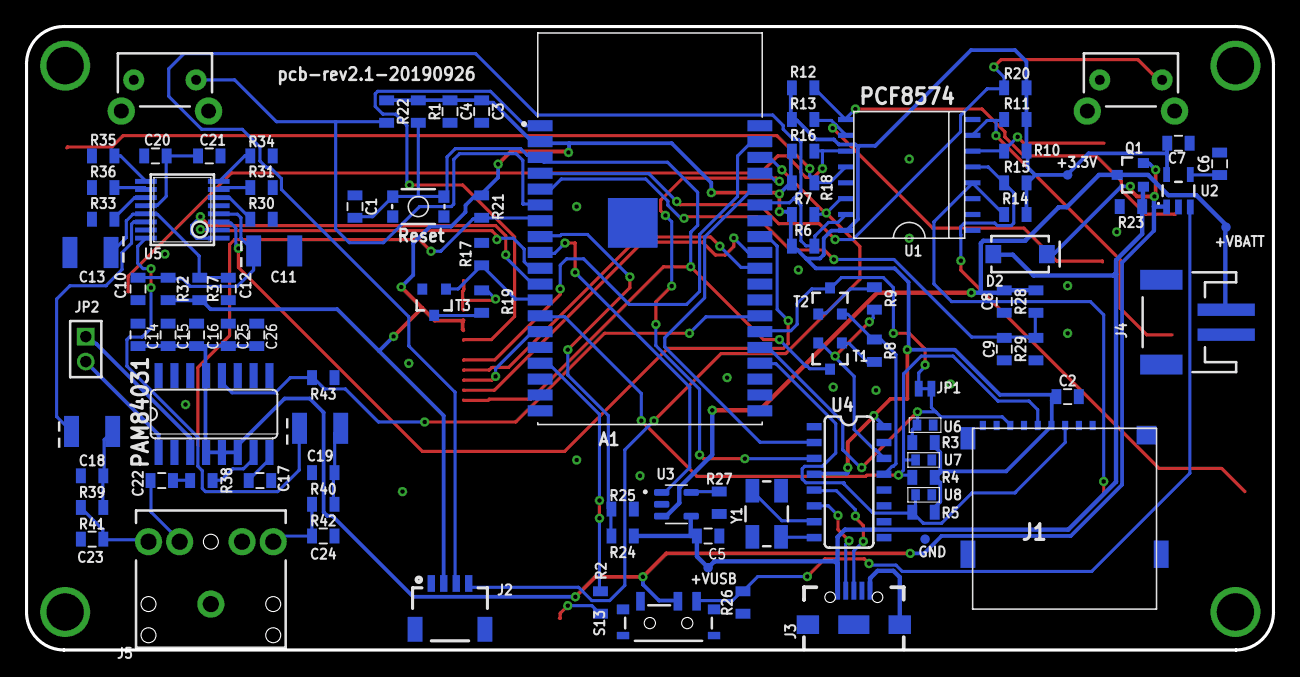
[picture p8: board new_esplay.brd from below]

Board: 2 copper layers, 100.0 x 50.0 mm, 118 parts (100 on the bottom side), 73 nets.

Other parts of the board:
U$1: OSHW-LOGO-M
U$2: USB_LOGO
U$3: HEADPHONE_LOGO

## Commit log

2019-05-06 Optimize vias and add amplifier
    [new_esplay.brd, new_esplay.sch]
2019-08-27 Updated to revision 2.0
    [new_esplay.brd, new_esplay.csv, new_esplay.sch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]
2019-08-29 final design rev2.0
    [new_esplay.brd, new_esplay.csv, new_esplay.sch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]
2019-10-28 bugs fix
    [new_esplay.brd, new_esplay.csv, new_esplay.sch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]
2019-11-25 bugs fix with R19 value
    [new_esplay.brd, new_esplay.csv, new_esplay.sch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]

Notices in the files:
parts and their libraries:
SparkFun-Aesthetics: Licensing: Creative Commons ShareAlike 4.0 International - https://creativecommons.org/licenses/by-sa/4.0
